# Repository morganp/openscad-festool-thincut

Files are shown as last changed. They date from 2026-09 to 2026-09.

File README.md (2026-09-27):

# OpenSCAD Festool Thin Cut

A parametric thin-cut (repeat strip) stop for a Festool FS / FS-2 guide rail.

The jig hooks a key into the T-slot on the **top face at the rail back edge**,
wraps down the outside of the back edge, and returns **under** the rail as a
thin leg lying in the workpiece plane. The inner end face of that leg is the
stop. Butt the workpiece edge against it and the strip under the rail is
exactly `cut_offset` (default 165mm) wide, cut after cut.

Version 0.4.0 ([Semantic Versioning 2.0.0](https://semver.org)).

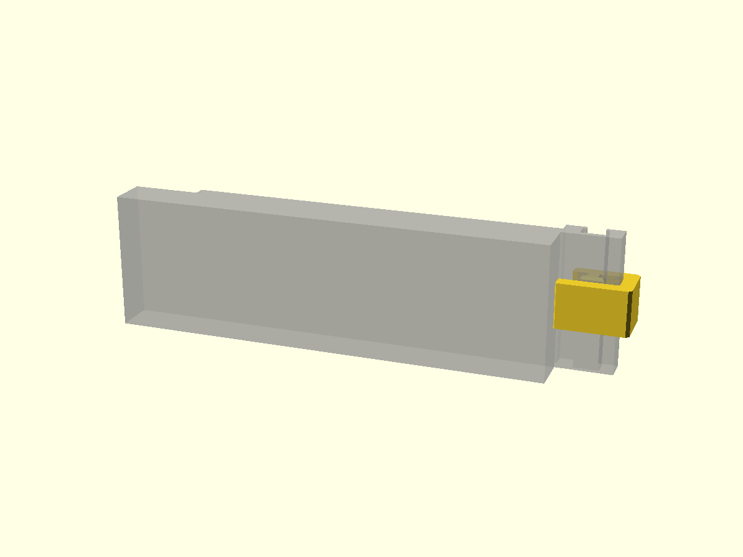
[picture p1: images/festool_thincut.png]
jig


## Requirements

- OpenSCAD 2021.01 or newer. No libraries (vanilla OpenSCAD).

## Section

Looking along the rail. Cutting edge on the left, back edge on the right.

```
  cutting edge                                  top T-slot   back edge
  x = 0                                             v            |
  |   _________________________________________ __  __ ___      |
  |  |              rail                       |  ||  |   |     |_
  |__|_________________________________________|__[key]___|    | | <- wall
 ======================== workpiece =======|STOP______________| |
 ==========================================|  under leg        |
                                           ^
                                  x = cut_offset (165)
```

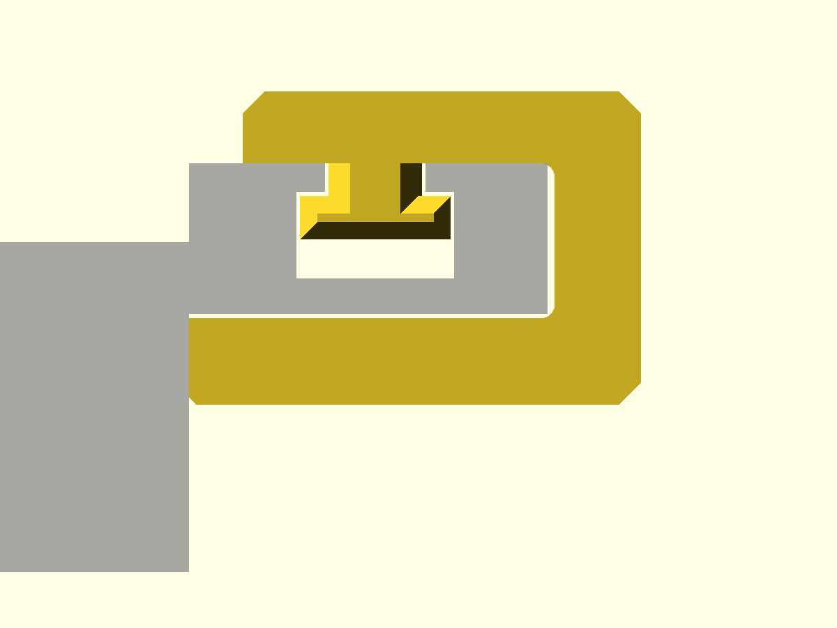
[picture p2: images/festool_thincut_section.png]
section


- `x = 0` is the cutting edge: the trimmed splinter guard, i.e. the blade face.
- `y = 0` is the rail underside, which is the workpiece top face.
- The **key is the locator**. It is a sliding fit in the slot. The wall only
  wraps the back edge with `edge_clr` clearance and does not locate.
- So the one dimension that sets the strip width is **cutting edge to the
  T-slot centreline**. Measure it and enter it as `slot_c_from_cut_measured`.
  Everything else derives from it.
- The under leg is made from `material_t` (thickness of the stock being
  cut) minus `under_clr`, so it stands on the bench and supports the rail
  without lifting it.

## Use

1. Slide the jig on from the end of the rail (T key), or drop it in from
   above (`key_style = "bar"`).
2. Set the rail on the workpiece with the workpiece edge against the stop.
3. Cut. The strip under the rail is `cut_offset` wide.

Two jigs, one near each end of the rail, register the rail parallel to the
workpiece edge. One jig alone only sets the width at one point.

## Parameters

The Customizer shows only three parameters:

| Parameter | Default | Range | Meaning |
|---|---|---|---|
| `cut_offset` | 165 | 10 to 168 | Strip width: rail cutting edge to stop face, embossed on the jig |
| `jig_len` | 20 | 10 to 100 | Jig length along the rail (print height) |
| `material_t` | 6.3 | 3 to 50 | Thickness of the stock being cut; sets the under leg |

Everything else sits under `[Hidden]` and is edited in the source. The
part is centred on the origin by default (`center_on_bed = true`); set it
false to keep rail coordinates for the `show_rail` / `show_workpiece` ghosts.

| Parameter | Default | Meaning |
|---|---|---|
| `part` | `"jig"` | `"jig"` or `"key_test"` (15mm slice of the key) |
| `show_rail`, `show_workpiece` | false | Ghosts for preview, not exported |
| `center_on_bed` | true | Part centred on the origin |
| `cut_offset` | 165 | Cutting edge to stop face = strip width, embossed on the bridge top |
| `offset_trim` | 0 | Fine tune after a test cut, + = wider strip |
| `jig_len` | 70 | Length along the rail (print height) |
| `rail_w` | 190 | Cutting edge to aluminium back edge. Calibrated by v0.1.0 test cut |
| `rail_back_h` | 10.5 | Underside to top face at the back edge. **Measure** |
| `slot_c_from_back` | 12 | Back edge to slot centreline. **Measure** |
| `slot_c_from_cut_measured` | 0 | Overrides the above if > 0. **Best single measurement** |
| `slot_open_w` | 8.0 | Slot opening between the lips. v0.1.0 neck was 1mm narrow |
| `slot_lip_t` | 2.0 | Lip thickness. **Measure** |
| `slot_under_w` | 11.0 | Undercut width. **Measure** |
| `slot_under_h` | 6.0 | Undercut height. **Measure** |
| `key_style` | `"T"` | `"T"` slides on from the end, `"bar"` drops in |
| `key_clr` | 0.25 | Per side sliding clearance in the slot |
| `key_vclr` | 0.3 | T head below the lip underside |
| `key_head_h` | 3.0 | T head height |
| `lead_cham` | 1.5 | Lead-in chamfer at both key ends |
| `bridge_t` | 5 | Bridge thickness above the rail |
| `wall_t` | 6 | Wall outside the back edge |
| `edge_clr` | 0.5 | Wall to rail back edge |
| `under_t` | derived | `material_t - under_clr` |
| `under_clr` | 0.3 | Under leg top below the rail underside |
| `inner_fillet` | 1.0 | Inner corner fillets |

Rail defaults are estimates. See `todo.md` for what to measure.

## Print settings

- Print as modelled: section face on the bed, rail direction vertical. Every
  layer holds the whole C, so the wrap and the key neck are strong. No
  supports.
- PETG or PLA, 0.4mm nozzle, 0.2mm layers, 4 walls, 30% infill.
- Print `part = "key_test"` first (a few minutes) and slide it along the
  rail. Adjust `key_clr` or the slot dimensions before printing the jig.
- The stop face is a vertical wall in print, so it is as accurate as the
  printer's XY. Keep it free of seams (set seam to the back / wall side).

## Files

- `festool_thincut.scad` the model
- `exports/festool_thincut_v0.2.0.stl`, `exports/festool_thincut_key_test_v0.2.0.stl`
- `images/` renders

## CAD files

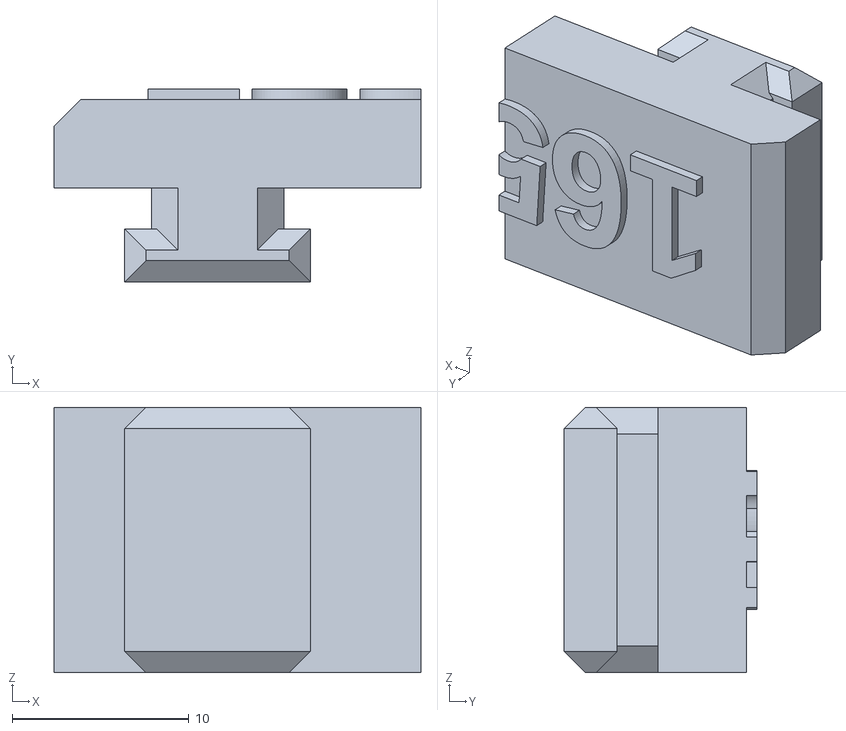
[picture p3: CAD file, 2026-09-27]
exports/festool_thincut_key_test_v0.2.0.stl
20.8 x 10.9 x 15.0

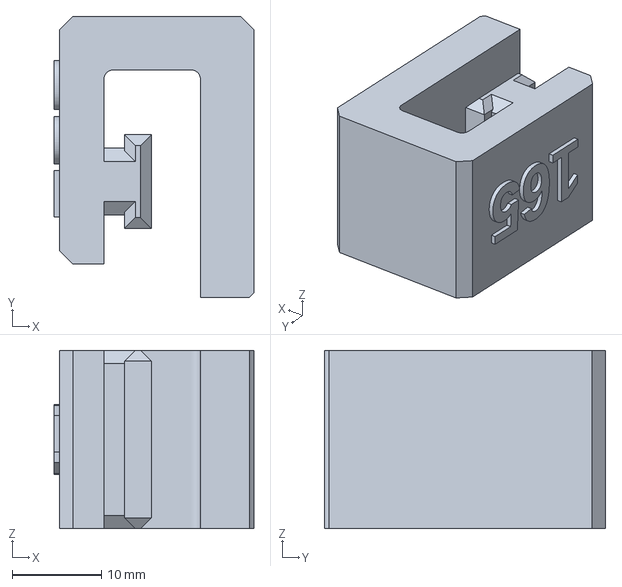
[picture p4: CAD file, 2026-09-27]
makerworld/festool_thincut_165mm.3mf
22.4 x 31.5 x 20.0 mm

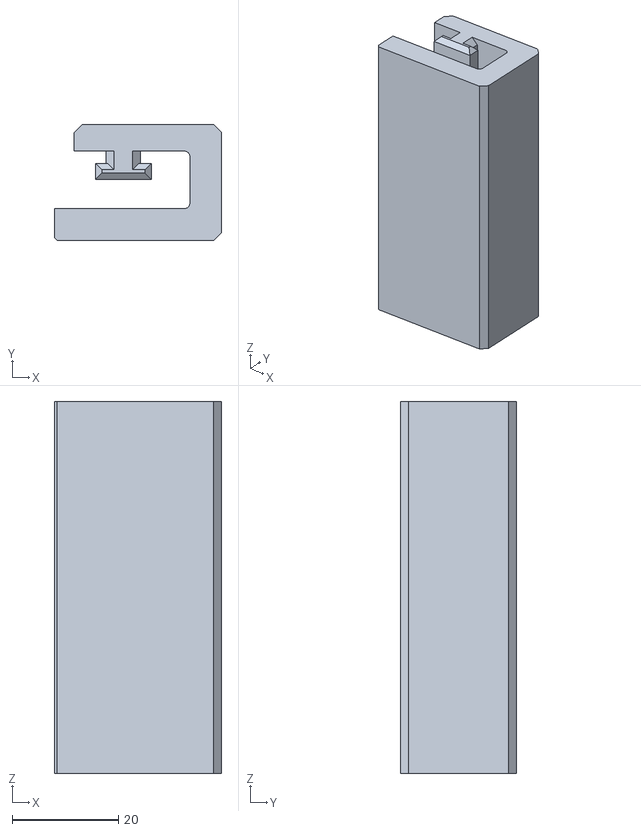
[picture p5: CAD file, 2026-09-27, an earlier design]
exports/festool_thincut_v0.1.0.stl
31.5 x 21.8 x 70.0

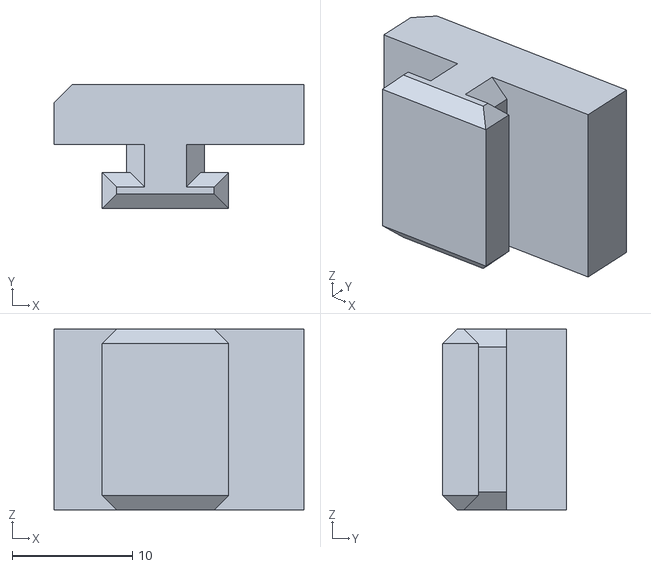
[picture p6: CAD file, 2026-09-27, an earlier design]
exports/festool_thincut_key_test_v0.1.0.stl
20.8 x 10.3 x 15.0

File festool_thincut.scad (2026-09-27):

//////////////////////////////////////////////////////////////////////////////
// festool_thincut.scad
//   Thin-cut (repeat strip) stop for a Festool FS / FS-2 guide rail.
//
// Library mode: vanilla OpenSCAD, no BOSL2.
//   The part is one 2D section extruded along the rail plus a chamfered
//   key. Nothing here needs BOSL2, so the file has no dependency.
//
// Section, looking along the rail (X across the rail, Y up):
//
//      cutting edge                               top T-slot   back edge
//      x = 0                                          v            |
//      |   ________________________________________ __  __ ___    |
//      |  |              rail (ghost)              |  ||  |   |   |_
//      |__|________________________________________|__[key]___|  | | <- wall
//  ======================== workpiece =========|STOP______________| |
//  ============================================|  under leg        |
//                                              ^
//                                     x = cut_offset (165)
//
//   The jig hooks a key into the T-slot on the TOP face at the rail back
//   edge, wraps down the outside of the back edge, and returns UNDER the
//   rail as a thin leg in the workpiece plane. The inner end face of that
//   leg is the stop. Butt the workpiece edge against it and the strip
//   under the rail is exactly cut_offset wide.
//
// Datum
//   x = 0 is the cutting edge (trimmed splinter guard = blade face).
//   y = 0 is the rail underside = workpiece top face.
//   The key in the slot is the lateral locator (tight fit). The wall only
//   wraps the back edge with edge_clr, it does not locate. So the one
//   measurement that sets the strip width is cutting edge to T-slot.
//   Measure it and put it in slot_c_from_cut_measured.
//
// Print orientation
//   Modelled as printed: section face flat on the bed, rail direction = Z.
//   Every layer holds the whole C, so the wrap and key neck carry load
//   along the extrusion lines. Prism, no supports. Key end chamfers are
//   45 degrees.
//
// Units: mm throughout.
// Version: 0.4.0
//////////////////////////////////////////////////////////////////////////////

/* [Jig] */
// Strip width in mm: rail cutting edge to the stop. Embossed on the jig.
cut_offset   = 165;   // [10:1:168]
// Jig length along the rail in mm (print height).
jig_len      = 20;    // [10:5:100]
// Thickness in mm of the material being cut. The leg under the rail is
// made to match, so it stands on the bench and supports the rail.
material_t   = 6.3;   // [3:0.1:50]

/* [Hidden] */
// Everything below is for fitting the jig to the rail. Edit in the source.

// v0.1.0 printed with 160 cut 165 on the real rail, so rail_w was 5 short.
// rail_w and cut_offset both +5 keep the printed geometry identical.
offset_trim  = 0;     // mm, + makes the strip wider. Tune after a test cut

part           = "jig";    // [jig, key_test]
show_rail      = false;    // ghost of the rail section
show_workpiece = false;    // ghost of the workpiece and strip
center_on_bed  = true;     // false: keep rail coords (x = 0 at cutting edge)

// Rail: MEASURE ON REAL RAIL ----------
// Cutting edge (trimmed splinter guard) to aluminium back edge.
// FOG forum: 183 aluminium + 2-3 splinter lip. v0.1.0 test cut (160 set,
// 165 cut) calibrates it to 190.
rail_w            = 190;   // mm
// Height from rail underside (incl. grip strips) to top face at the back
// edge, where the jig bridge sits. Estimate.
rail_back_h       = 10.5;  // mm
// Width of the thick back section of the extrusion (ghost only). Estimate.
rail_back_w       = 25;    // mm
// Plate thickness away from the back section (ghost only). Estimate.
rail_plate_t      = 5;     // mm
// T-slot on the TOP face near the back edge ("ceiling facing" track).
slot_c_from_back  = 12;    // mm, back edge to slot centreline. Estimate
// Set to a measured cutting edge to slot centreline distance to override
// rail_w - slot_c_from_back. 0 = derive.
slot_c_from_cut_measured = 0;  // mm
slot_open_w       = 8.0;   // mm, opening between the lips. v0.1.0 neck 1mm narrow
slot_lip_t        = 2.0;   // mm, lip thickness. Estimate
slot_under_w      = 11.0;  // mm, undercut width. Estimate
slot_under_h      = 6.0;   // mm, undercut height, FOG: 6mm nut slides in

// Key ----------
key_style   = "T";   // [T:T key slides on from the rail end, bar:neck only drops in from above]
key_clr     = 0.25;  // mm per side, sliding fit in the slot
key_vclr    = 0.3;   // mm, T head below the lip underside
key_head_h  = 3.0;   // mm, T head height (less than slot_under_h)
bar_depth   = 1.5;   // mm, bar key reach below the lip underside
lead_cham   = 1.5;   // mm, lead-in chamfer at both key ends

// Body ----------
bridge_t     = 5;     // mm, bridge thickness above the rail top
bridge_past  = 4;     // mm, bridge beyond the key towards the cutting edge
wall_t       = 6;     // mm, vertical leg outside the back edge
edge_clr     = 0.5;   // mm, wall to rail back edge. Does not locate
// Under leg: material_t minus under_clr, so its top sits just below the
// rail and never lifts it. v0.1.0 to v0.3.0 printed 6 thick = material_t 6.3.
under_clr    = 0.3;   // mm, leg top below rail underside
under_t      = material_t - under_clr;   // mm
stop_cham    = 0.5;   // mm, small chamfer at the stop bottom edge
outer_cham   = 1.5;   // mm, outer corners of the C
inner_fillet = 1.0;   // mm, inner corners. 0.29*r intrudes, keep < edge_clr/0.29

// Label ----------
show_label   = true;  // emboss the cut width on the bridge top
label_size   = 8;     // mm, text height
label_h      = 0.6;   // mm, emboss height

// Key test coupon ----------
key_test_len = 15;    // mm

$fn = 64;
EPS = 0.01;

//////////////////////////////////////////////////////////////////////////////
// Derived
//////////////////////////////////////////////////////////////////////////////
slot_c   = slot_c_from_cut_measured > 0 ? slot_c_from_cut_measured
                                        : rail_w - slot_c_from_back;
x_stop   = cut_offset + offset_trim;
x_wall_i = rail_w + edge_clr;          // wall inner face
x_wall_o = x_wall_i + wall_t;          // wall outer face
y_leg_t  = -under_clr;                 // under leg top
y_leg_b  = y_leg_t - under_t;          // under leg bottom
y_top    = rail_back_h;                // rail top at the back, bridge bottom
y_bridge = y_top + bridge_t;           // jig top
y_lip_u  = y_top - slot_lip_t;         // lip underside
neck_w   = slot_open_w - 2 * key_clr;
head_w   = slot_under_w - 2 * key_clr;
y_head_t = y_lip_u - key_vclr;
y_head_b = y_head_t - key_head_h;
y_key_b  = key_style == "T" ? y_head_b : y_lip_u - bar_depth;
key_w_max = key_style == "T" ? head_w : neck_w;
x_bridge = slot_c - key_w_max / 2 - bridge_past;   // bridge inner end

echo(str("slot centre from cutting edge = ", slot_c));
echo(str("stop face from cutting edge   = ", x_stop));
echo(str("stop inboard of back edge     = ", rail_w - x_stop));
echo(str("under leg thickness           = ", under_t));

assert(x_stop < x_bridge, "stop must lie inboard of the bridge / key");
assert(x_stop < rail_w - 5, "stop too close to the rail back edge");
assert(key_style != "T" || key_head_h + key_vclr < slot_under_h,
       "T head does not fit the undercut height");
assert(neck_w > 1.2, "key neck thinner than a printable wall");
assert(under_t >= 2, "material_t too thin for a printable under leg");

//////////////////////////////////////////////////////////////////////////////
// 2D sections
//////////////////////////////////////////////////////////////////////////////

// C body without the key. Concave corners filleted, outer corners chamfered.
module body_2d() {
    oc = outer_cham;
    pts = [
        [x_stop,             y_leg_b + stop_cham],
        [x_stop + stop_cham, y_leg_b],
        [x_wall_o - oc,      y_leg_b],
        [x_wall_o,           y_leg_b + oc],
        [x_wall_o,           y_bridge - oc],
        [x_wall_o - oc,      y_bridge],
        [x_bridge + oc,      y_bridge],
        [x_bridge,           y_bridge - oc],
        [x_bridge,           y_top],
        [x_wall_i,           y_top],
        [x_wall_i,           y_leg_t],
        [x_stop,             y_leg_t]
    ];
    if (inner_fillet > 0)
        offset(r = -inner_fillet) offset(delta = inner_fillet) polygon(pts);
    else
        polygon(pts);
}

// Rail ghost. Only the back section is meant to be dimensionally useful.
module rail_2d() {
    difference() {
        union() {
            square([rail_w, rail_plate_t]);
            translate([rail_w - rail_back_w, 0]) square([rail_back_w, rail_back_h]);
        }
        // top T-slot
        translate([slot_c - slot_open_w / 2, y_lip_u - EPS])
            square([slot_open_w, slot_lip_t + 2 * EPS]);
        translate([slot_c - slot_under_w / 2, y_lip_u - slot_under_h])
            square([slot_under_w, slot_under_h]);
    }
}
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

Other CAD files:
exports/festool_thincut_v0.2.0.stl

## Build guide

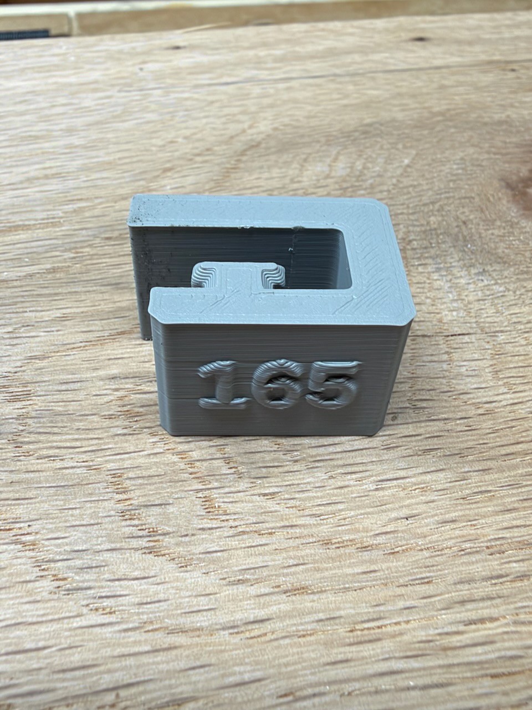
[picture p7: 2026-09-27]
makerworld/cover_3x4.jpeg

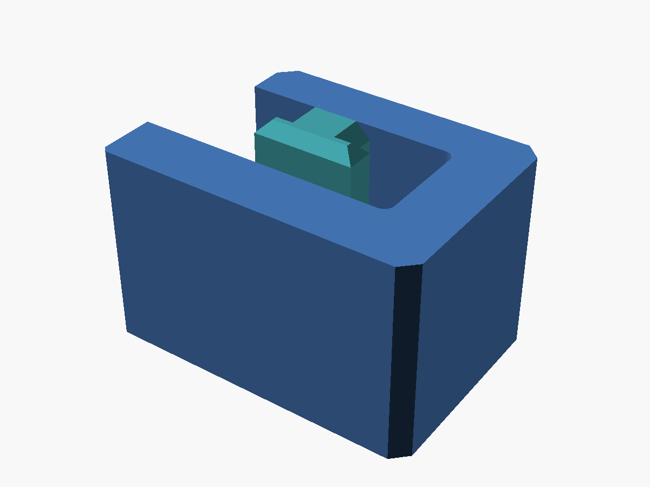
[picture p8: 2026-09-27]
makerworld/view_iso.png

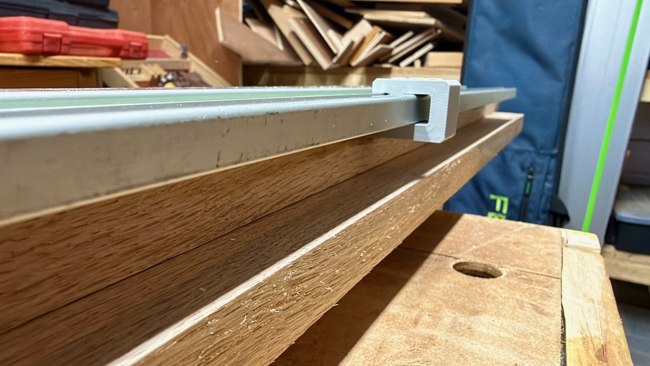
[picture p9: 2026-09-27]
makerworld/photo_2933.jpeg

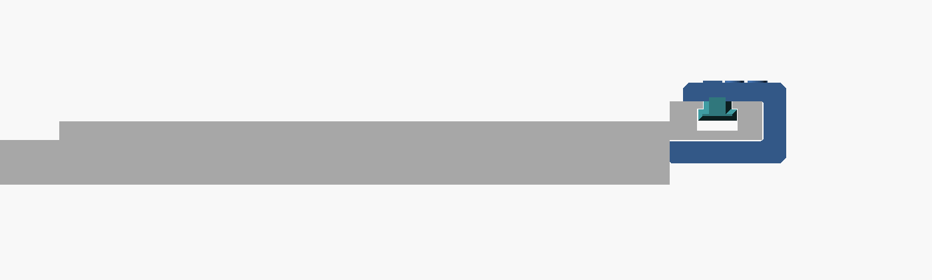
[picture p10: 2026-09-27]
makerworld/view_end.png

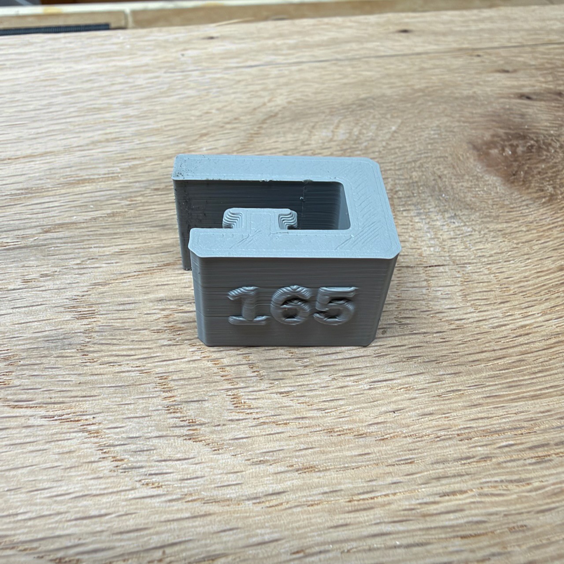
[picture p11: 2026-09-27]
makerworld/photo_2936.jpeg

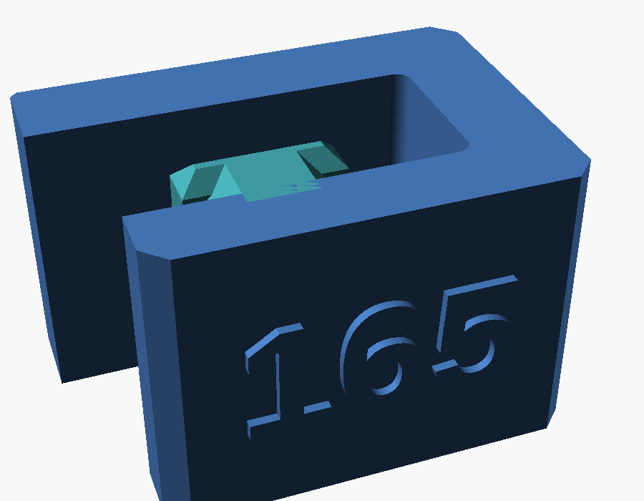
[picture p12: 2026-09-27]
makerworld/view_top.png

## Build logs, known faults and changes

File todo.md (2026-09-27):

# Festool Thin Cut - todo

## Done (v0.1.0)
- [x] Parametric C jig: T key in the top back-edge slot, wall round the back
      edge, under leg with the stop at `cut_offset` 160 from the cutting edge
- [x] Stop position derived from the slot centreline, with
      `slot_c_from_cut_measured` as a one-number override
- [x] `key_style` T (slides on from the rail end) or bar (drops in)
- [x] `part = "key_test"` 15mm coupon to prove the slot fit first
- [x] Rail and workpiece ghosts, section and 3D renders, STLs exported

## Measure on real rail
Rail dimensions are estimates. Web sources only gave: about 183mm of
aluminium plus a 2-3mm splinter lip (FOG forum), and a nut 6mm thick or
less slides in the top ("ceiling facing") track (FOG forum). No published
drawing with slot numbers was reachable.
- [ ] **Cutting edge to T-slot centreline** (measure to both slot walls,
      average). This sets the strip width. Enter as `slot_c_from_cut_measured`
- [x] Cutting edge to aluminium back edge (`rail_w` 190, from v0.1.0 test cut: 160 set gave 165)
- [x] Slot opening width (`slot_open_w` 8.0, v0.1.0 neck 1mm narrow, >1mm play OK)
- [ ] Lip thickness (`slot_lip_t`, guess 2.0)
- [ ] Undercut width (`slot_under_w`, guess 11.0)
- [ ] Undercut height (`slot_under_h`, guess 6.0)
- [ ] Back edge to slot centreline (`slot_c_from_back`, guess 12)
- [ ] Rail height at the back edge, underside grip strips included
      (`rail_back_h`, guess 10.5)
- [ ] Confirm the top slot is open along the full rail length so a T key
      can slide on from the end. If it is not, use `key_style = "bar"`
- [ ] Check the back edge profile is square below the slot. If it has a
      bead or step, the wall needs a matching relief

## Open
- [ ] Print `key_test`, tune `key_clr` (0.25 per side is a guess)
- [ ] Print the jig, cut a test strip, measure, correct with `offset_trim`
- [ ] Decide on two jigs per rail (one each end) for parallel strips
- [ ] Under leg 6mm: fine for 12mm stock and up. For 6mm ply set
      `under_t` 4 or less
- [ ] Stop face is 6mm tall. Consider a taller stop (leg pads that reach
      below the rail line) only if thin strips ride over it
- [ ] Underside grip strips on the rail may not be at the back edge. If the
      rail rocks, add a pad to the under leg top

## Done (v0.2.0)
- [x] Key neck 1mm wider (`slot_open_w` 7 to 8)
- [x] Calibrated: `rail_w` 190, `cut_offset` 165. Stop, wall and bridge sit where v0.1.0 had them relative to the key
- [x] Cut width (`x_stop`) embossed on the bridge top (`show_label`)

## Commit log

2026-09-27 Festool thin cut jig v0.1.0
    Parametric C jig for a Festool FS rail. A T key in the top back-edge
    slot locates it, a wall wraps the back edge and an under leg carries
    the stop at cut_offset 160 from the cutting edge. Rail dimensions are
    estimates, listed in todo.md to measure. Includes a key test coupon.
    [festool_thincut.scad, festool_thincut_key_test_v0.1.0.stl, festool_thincut_v0.1.0.stl]
2026-09-27 Widen key neck 1mm, calibrate to 165mm cut, emboss cut width
    v0.1.0 printed at cut_offset 160 cut 165 on the real rail. rail_w and
    cut_offset both +5 keep the printed geometry; label shows x_stop.
    [festool_thincut.scad, festool_thincut_key_test_v0.2.0.stl, festool_thincut_v0.2.0.stl]
2026-09-27 Add center_on_bed option for online customizers
    Placement only; part shape unchanged from v0.2.0.
    [festool_thincut.scad]
2026-09-27 Customizer shows only strip width and jig length
    All rail fitting parameters move under [Hidden]. Part centred and
    ghosts off by default. Geometry identical to v0.2.1 centred.
    [festool_thincut.scad]
2026-09-27 Add MakerWorld upload bundle
    3mf print profile (165mm), customizer scad (v0.3.0), EXIF-stripped
    photos, cover crops and renders as uploaded to MakerWorld model 3363697.
    [festool_thincut.scad, festool_thincut_165mm.3mf]
2026-09-27 Add material_t customizer parameter for the under leg
    Under leg is material_t minus under_clr so it stands on the bench and
    supports the rail. Default 6.3 reproduces the printed 6mm leg exactly.
    [festool_thincut.scad]
